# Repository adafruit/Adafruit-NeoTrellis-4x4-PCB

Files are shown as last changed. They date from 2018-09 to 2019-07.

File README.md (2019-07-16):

## Adafruit NeoTrellis RGB Driver PCB for 4x4 Keypad PCB

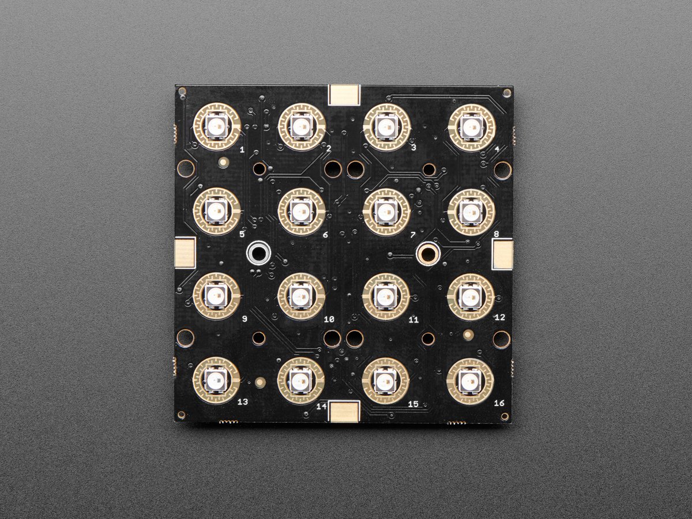
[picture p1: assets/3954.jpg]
<a href="http://www.adafruit.com/products/3954"><br/>
Click here to purchase one from the Adafruit shop</a>

PCB files for the Adafruit NeoTrellis RGB Driver PCB for 4x4 Keypad. Format is EagleCAD schematic and board layout
* https://www.adafruit.com/product/3954

### Description

By popular request, we've upgraded our popular Trellis elastomer button kits to now have a PCB with full color NeoPixel support! You heard that right, no more single-color LEDs, you can now have any color you like under the fantastic rubbery button pads we sell.

These 4x4 button pad boards are fully tile-able and communicate over I2C. With 5 address pins, you've got the ability to connect up to 32 together in any arrangement you like. [With our trusty seesaw I2C-to-anything chip](https://learn.adafruit.com/adafruit-seesaw-atsamd09-breakout), you don't even need to manage the NeoPixel driving. That's right! Both the button management and LED driving is completely handled for you all over plain I2C. With both Arduino/C++ and CircuitPython/Python library support, you can use these pads with any and all microcontroller or computer boards.

Perfect for your next cool interface, MIDI instrument, control panel...whatever could benefit from beautiful diffused colorful buttons. For fast connection to a single board, we include a JST-PH 4-pin connector that will give you power+data access. It's Grove compatible (the cable fits, even though its not the exact same connector), [or you can use a JST-PH 4 pin cable](https://www.adafruit.com/product/3568).

**You can tile up to 32 boards together by soldering them edge-to-edge and soldering closed the I2C address jumpers, then use one I2C connection for all tiled NeoTrellis boards!**

Each order comes with one NeoTrellis board with seesaw chip and 16 NeoPixels already soldered in place. **Elastomer button pad not included**, [so be sure to pick one up!](https://www.adafruit.com/product/1611)

### License

Adafruit invests time and resources providing this open source design, please support Adafruit and open-source hardware by purchasing products from [Adafruit](https://www.adafruit.com)!

Designed by Limor Fried/Ladyada for Adafruit Industries.

Creative Commons Attribution/Share-Alike, all text above must be included in any redistribution. See license.txt for additional details.

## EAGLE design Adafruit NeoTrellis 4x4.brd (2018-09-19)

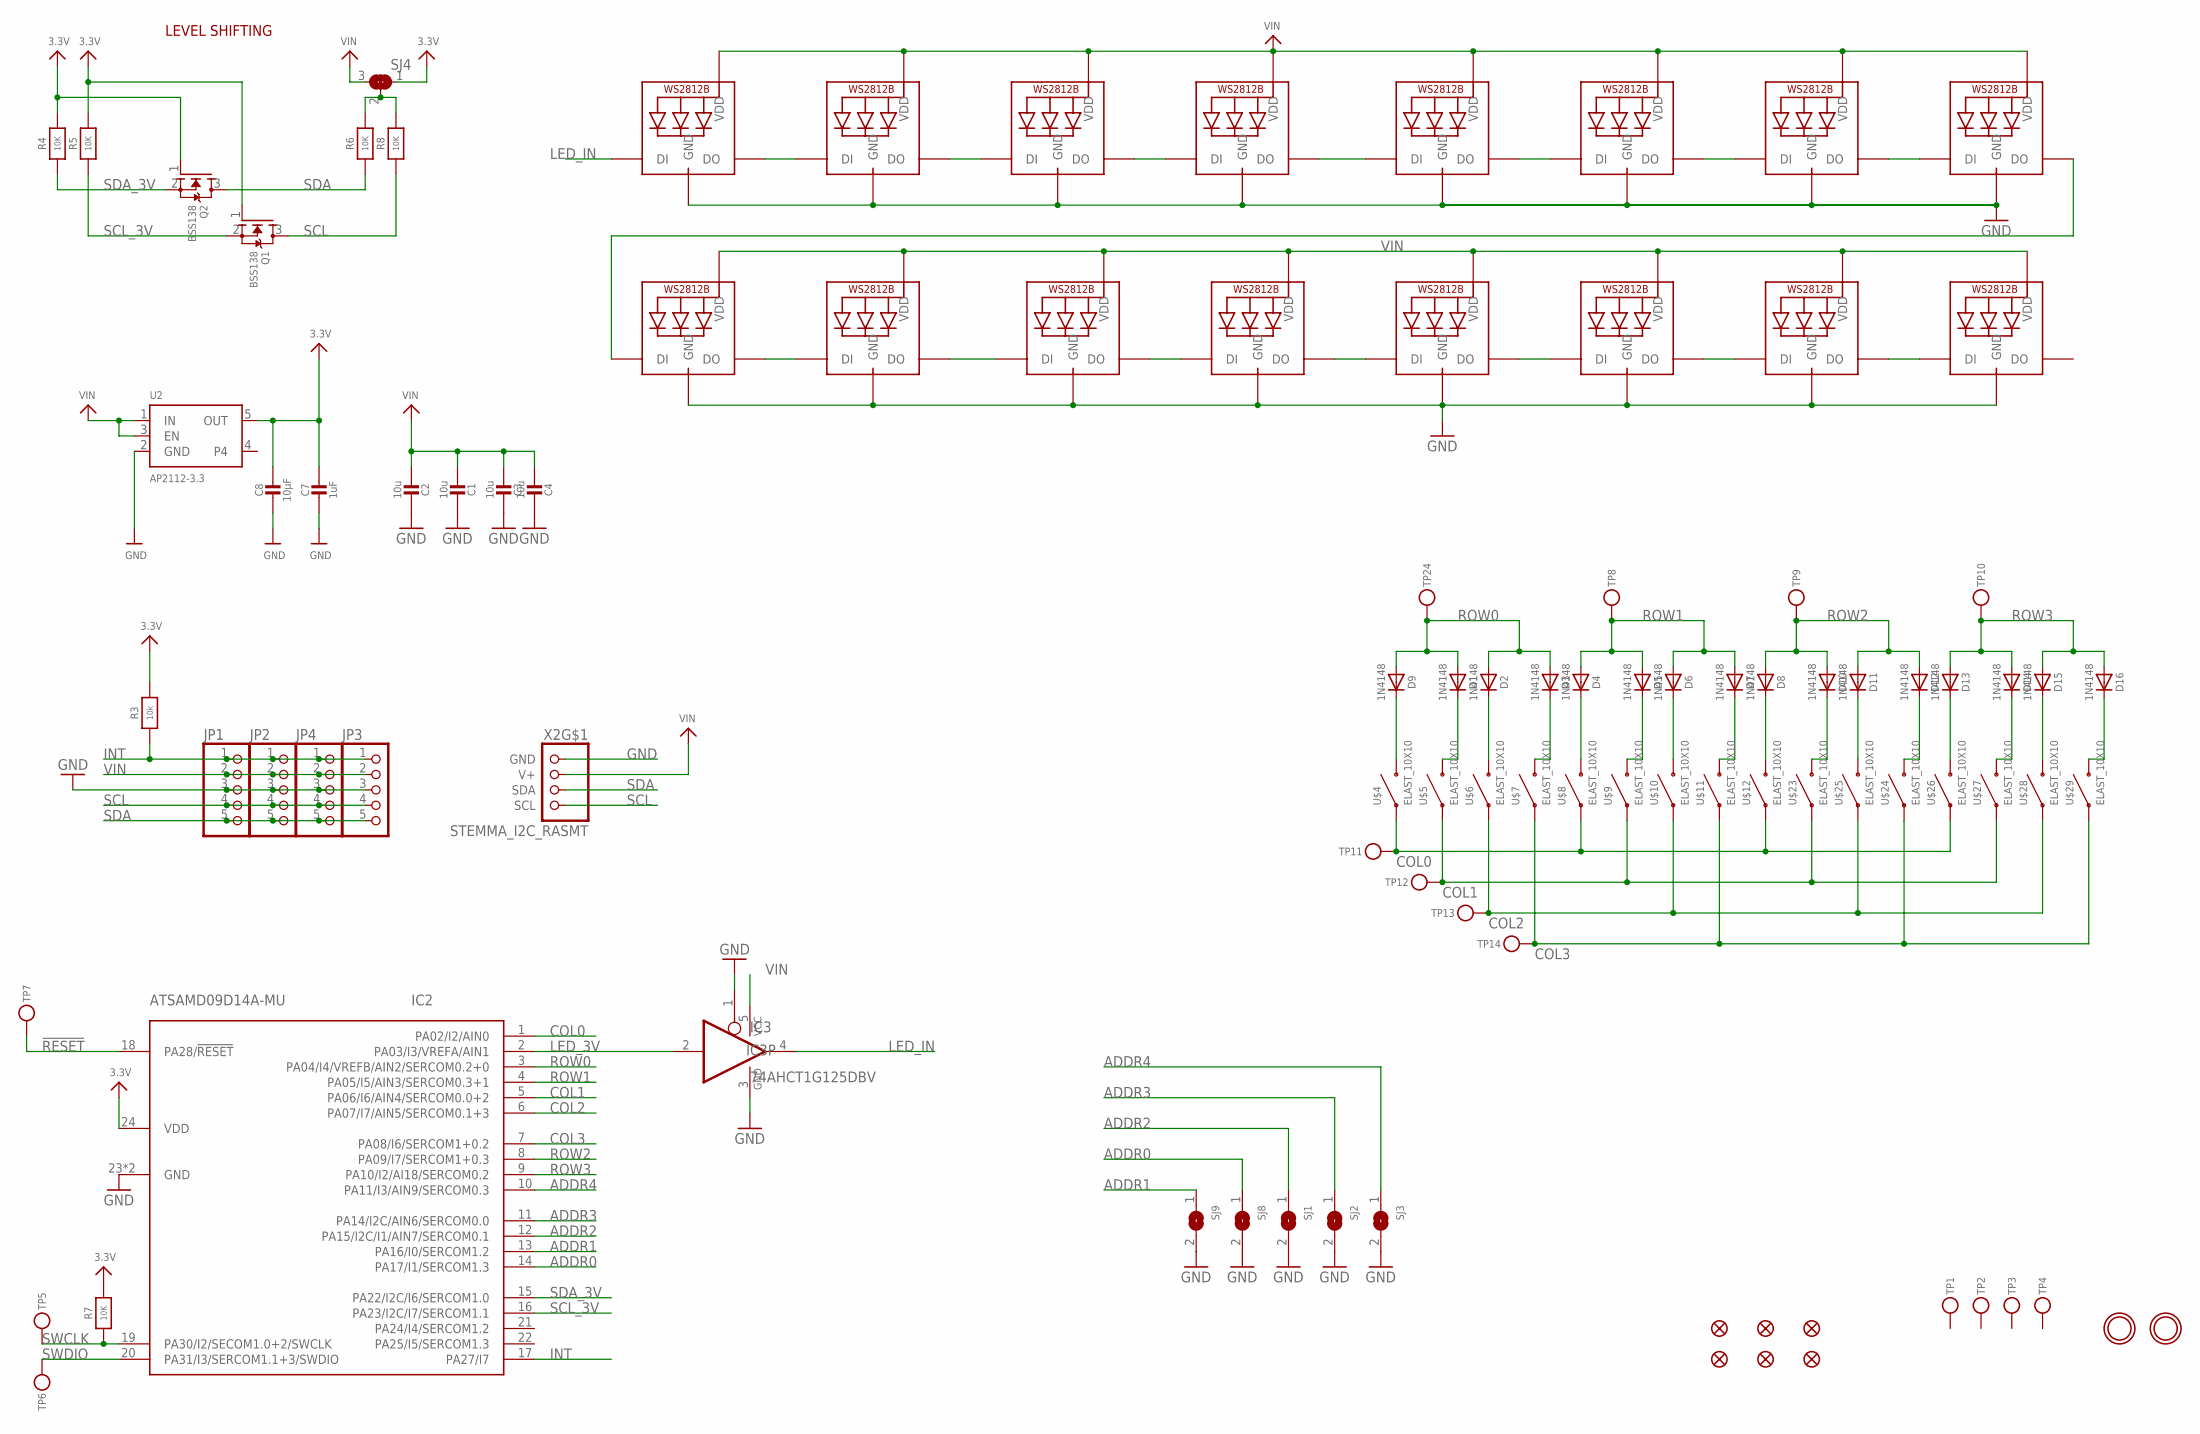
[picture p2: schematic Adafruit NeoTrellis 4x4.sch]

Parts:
C1, C2, C3, C4: 10u; 0805-NO
C7: 1uF; 0603-NO
C8: 10µF; 0805-NO
D1, D2, D3, D4, D5, D6, D7, D8, D9, D10, D11, D12, D13, D14, D15, D16: 1N4148; SOD-323
FID1, FID2, FID3, FID4, FID5, FID6: FIDUCIAL_1MM
IC2: ATSAMD09D14A-MU; QFN24_4MM
IC3: 74AHCT1G125DBV; SOT23-5
JP1, JP2, JP3, JP4: HEADER-1X5EDGESMT; 5P_EDGECONNECT
LED1, LED2, LED3, LED4, LED5, LED6, LED7, LED8, LED9, LED10, LED11, LED12, LED13, LED14, LED15, LED16: WS2812B3535; LED3535
Q1, Q2: BSS138; SOT23-WIDE
R3: 10k; 0603-NO
R4, R5, R6, R7, R8: 10K; 0603-NO
SJ1, SJ2, SJ3, SJ8, SJ9: SOLDERJUMPER; SOLDERJUMPER_ARROW_NOPASTE
SJ4: SOLDERJUMPER_2WAY; SOLDERJUMPER_2WAY_OPEN_NOPASTE
TP1, TP2, TP3, TP4: TESTPOINT; TESTPOINT_SMT
TP5, TP6: TESTPOINTROUND2MM; TESTPOINT_ROUND_2MM
TP7, TP8, TP9, TP10, TP11, TP12, TP13, TP14, TP24: TESTPOINTROUND1.5MM; TESTPOINT_ROUND_1.5MM
U2: AP2112-3.3; SOT23-5
U$1, U$2: MOUNTINGHOLE2.5; MOUNTINGHOLE_2.5_PLATED
U$4, U$5, U$6, U$7, U$8, U$9, U$10, U$11, U$12, U$23, U$24, U$25, U$26, U$27, U$28, U$29: ELAST_10X10; ELAST_PAD_SQUARE_10MM_4X4WIDE
X2: STEMMA_I2C_RASMT; JSTPH4

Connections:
3.3V: C7.1, C8.1, IC2.24 (VDD), Q1.1 (G), Q2.1 (G), R3.2, R4.2, R5.2, R7.2, SJ4.1, U2.5 (OUT)
!RESET: IC2.18 (PA28/!RESET), TP7.P$1
ADDR0: IC2.14 (PA17/I1/SERCOM1.3), SJ8.1
ADDR1: IC2.13 (PA16/I0/SERCOM1.2), SJ9.1
ADDR2: IC2.12 (PA15/I2C/I1/AIN7/SERCOM0.1), SJ1.1
ADDR3: IC2.11 (PA14/I2C/AIN6/SERCOM0.0), SJ2.1
ADDR4: IC2.10 (PA11/I3/AIN9/SERCOM0.3), SJ3.1
COL0: IC2.1 (PA02/I2/AIN0), TP11.P$1, U$4.P$1, U$8.P$1, U$12.P$1, U$26.P$1
COL1: IC2.5 (PA06/I6/AIN4/SERCOM0.0+2), TP12.P$1, U$5.P$1, U$9.P$1, U$23.P$1, U$27.P$1
COL2: IC2.6 (PA07/I7/AIN5/SERCOM0.1+3), TP13.P$1, U$6.P$1, U$10.P$1, U$25.P$1, U$28.P$1
COL3: IC2.7 (PA08/I6/SERCOM1+0.2), TP14.P$1, U$7.P$1, U$11.P$1, U$24.P$1, U$29.P$1
GND: C1.1, C2.1, C3.1, C4.1, C7.2, C8.2, IC2.23 (GND), IC2.THERM (GND), IC3.1 (OE), IC3.3 (GND), JP1.3, JP2.3, JP3.3, JP4.3, LED1.4 (GND), LED2.4 (GND), LED3.4 (GND), LED4.4 (GND), LED5.4 (GND), LED6.4 (GND), LED7.4 (GND), LED8.4 (GND), LED9.4 (GND), LED10.4 (GND), LED11.4 (GND), LED12.4 (GND), LED13.4 (GND), LED14.4 (GND), LED15.4 (GND), LED16.4 (GND), SJ1.2, SJ2.2, SJ3.2, SJ8.2, SJ9.2, U2.2 (GND), X2.1 (GND)
INT: IC2.17 (PA27/I7), JP1.1, JP2.1, JP3.1, JP4.1, R3.1
LED_3V: IC2.2 (PA03/I3/VREFA/AIN1), IC3.2 (I)
LED_IN: IC3.4 (O), LED1.1 (DI)
unnamed: R6.2, R8.2, SJ4.2
unnamed: D9.C, U$4.P$2
unnamed: D1.C, U$5.P$2
unnamed: D2.C, U$6.P$2
unnamed: D3.C, U$7.P$2
unnamed: D4.C, U$8.P$2
unnamed: D5.C, U$9.P$2
unnamed: LED1.3 (DO), LED2.1 (DI)
unnamed: LED2.3 (DO), LED3.1 (DI)
unnamed: LED3.3 (DO), LED4.1 (DI)
unnamed: LED4.3 (DO), LED5.1 (DI)
unnamed: D6.C, U$10.P$2
unnamed: LED5.3 (DO), LED6.1 (DI)
unnamed: LED6.3 (DO), LED7.1 (DI)
unnamed: D7.C, U$11.P$2
unnamed: LED7.3 (DO), LED8.1 (DI)
unnamed: D8.C, U$12.P$2
unnamed: LED8.3 (DO), LED9.1 (DI)
unnamed: D10.C, U$23.P$2
unnamed: D11.C, U$25.P$2
unnamed: D12.C, U$24.P$2
unnamed: D13.C, U$26.P$2
unnamed: D14.C, U$27.P$2
unnamed: D15.C, U$28.P$2
unnamed: D16.C, U$29.P$2
unnamed: LED9.3 (DO), LED10.1 (DI)
unnamed: LED10.3 (DO), LED12.1 (DI)
unnamed: LED11.1 (DI), LED12.3 (DO)
unnamed: LED11.3 (DO), LED13.1 (DI)
unnamed: LED13.3 (DO), LED14.1 (DI)
unnamed: LED14.3 (DO), LED15.1 (DI)
unnamed: LED15.3 (DO), LED16.1 (DI)
ROW0: D1.A, D2.A, D3.A, D9.A, IC2.3 (PA04/I4/VREFB/AIN2/SERCOM0.2+0), TP24.P$1
ROW1: D4.A, D5.A, D6.A, D7.A, IC2.4 (PA05/I5/AIN3/SERCOM0.3+1), TP8.P$1
ROW2: D8.A, D10.A, D11.A, D12.A, IC2.8 (PA09/I7/SERCOM1+0.3), TP9.P$1
ROW3: D13.A, D14.A, D15.A, D16.A, IC2.9 (PA10/I2/AI18/SERCOM0.2), TP10.P$1
SCL: JP1.4, JP2.4, JP3.4, JP4.4, Q1.3 (D), R8.1, X2.4 (SCL)
SCL_3V: IC2.16 (PA23/I2C/I7/SERCOM1.1), Q1.2 (S), R5.1
SDA: JP1.5, JP2.5, JP3.5, JP4.5, Q2.3 (D), R6.1, X2.3 (SDA)
SDA_3V: IC2.15 (PA22/I2C/I6/SERCOM1.0), Q2.2 (S), R4.1
SWCLK: IC2.19 (PA30/I2/SECOM1.0+2/SWCLK), R7.1, TP5.P$1
SWDIO: IC2.20 (PA31/I3/SERCOM1.1+3/SWDIO), TP6.P$1
VIN: C1.2, C2.2, C3.2, C4.2, IC3.5 (VCC), JP1.2, JP2.2, JP3.2, JP4.2, LED1.2 (VDD), LED2.2 (VDD), LED3.2 (VDD), LED4.2 (VDD), LED5.2 (VDD), LED6.2 (VDD), LED7.2 (VDD), LED8.2 (VDD), LED9.2 (VDD), LED10.2 (VDD), LED11.2 (VDD), LED12.2 (VDD), LED13.2 (VDD), LED14.2 (VDD), LED15.2 (VDD), LED16.2 (VDD), SJ4.3, U2.1 (IN), U2.3 (EN), X2.2 (V+)

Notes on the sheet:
LEVEL SHIFTING

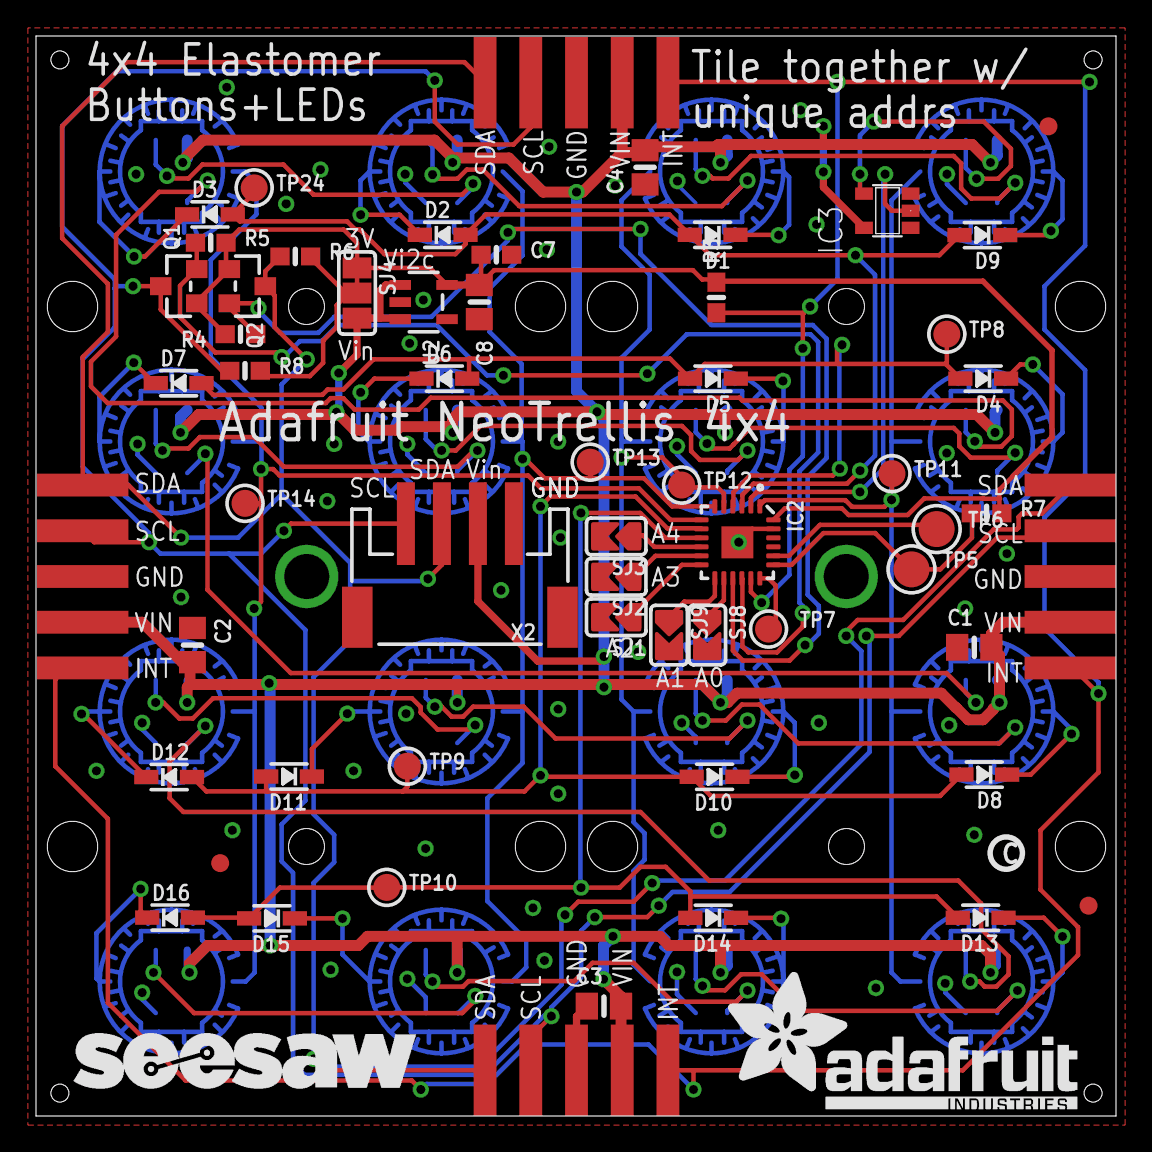
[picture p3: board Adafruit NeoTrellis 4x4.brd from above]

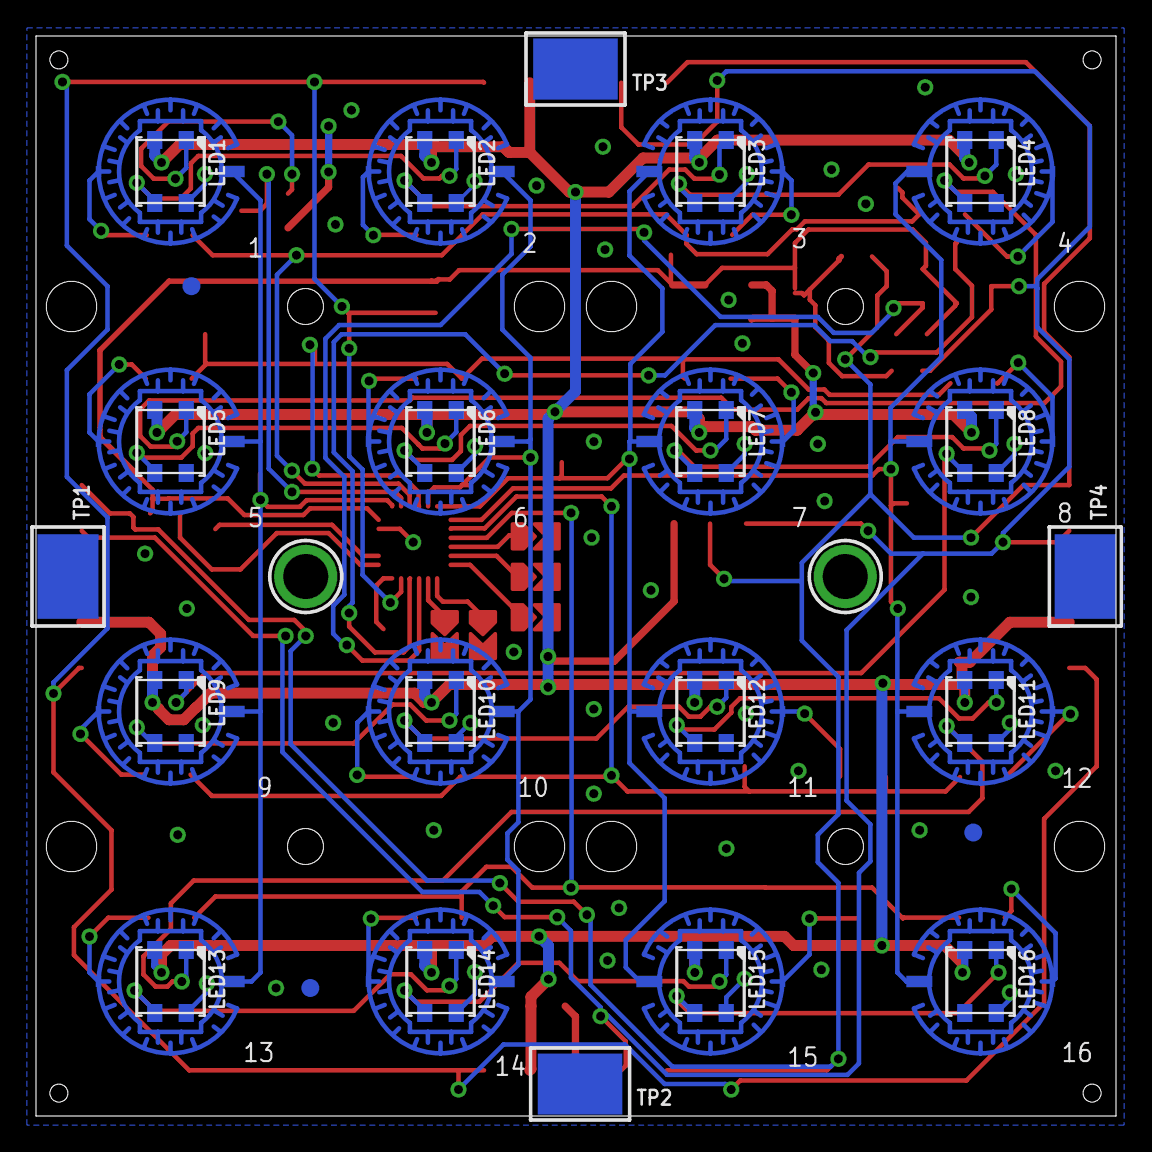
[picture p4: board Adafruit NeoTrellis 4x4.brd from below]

Board: 2 copper layers, 60.0 x 60.0 mm, 102 parts (41 on the bottom side), 58 nets.

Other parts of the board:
U$3: ADAFRUIT_TEXT_20MM
U$14: SEESAW_LOGO
U$19: PCBFEAT-REV-040

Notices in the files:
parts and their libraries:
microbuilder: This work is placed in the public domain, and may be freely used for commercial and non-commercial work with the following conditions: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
